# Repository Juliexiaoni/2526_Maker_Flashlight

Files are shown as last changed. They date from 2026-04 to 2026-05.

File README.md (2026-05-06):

# 2526_Maker_Flashlight
Objectif : Concevoir une lampe d'éclairage sur un vélo afin d'augmenter la sécutité en étant plus visible. 

### Cahier des charges : 
- 3 modes d’éclairages
- Étanche
- Bonus pour le rendre avancée : énergie solaire, allumage automatique (capteur luminosité)

### Planning prévisionnel : 
1. Etablir une analyse fonctionnelle et la BOM
2. Schématique et routage conception électronique
3. CAO pour le boitier
4. Assemblage et test

Le boîtier consiste à réaliser un suppport qui se clipse sur une attache en caoutchouc. 
Support Flashlight

WhatsApp Image 2026-05-06 at 15 49 47 (1)
WhatsApp Image 2026-05-06 at 15 49 47
WhatsApp Image 2026-05-06 at 15 54 11

La distance laissée entre les composants de la couche arrière et le support permet d’utiliser le bouton pour allumer et éteindre la lumière.

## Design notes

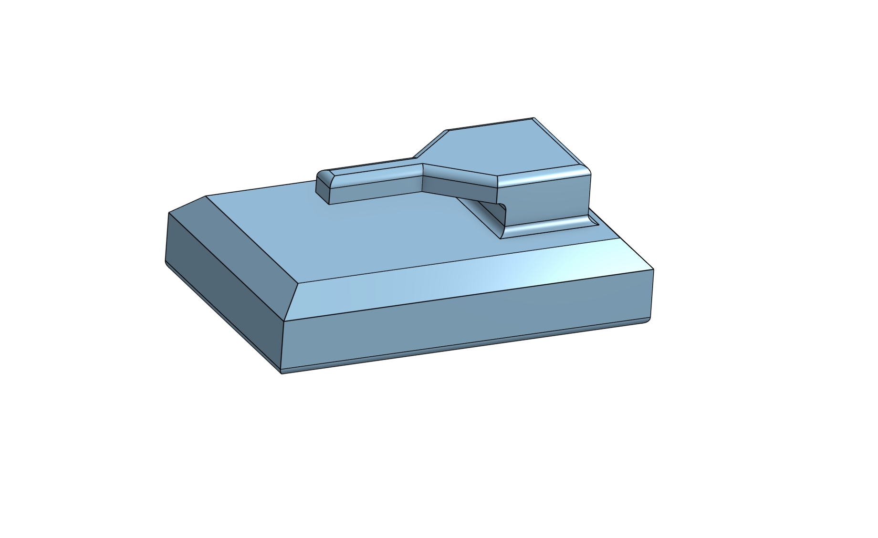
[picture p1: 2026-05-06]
Impression 3D/Support Flashlight.png

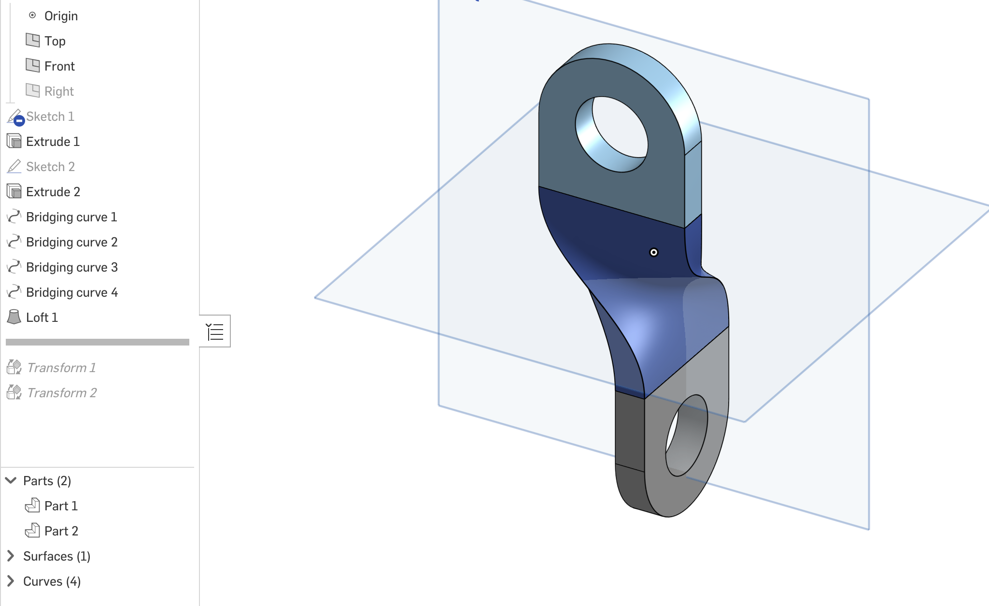
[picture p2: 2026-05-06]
Impression 3D/Exercice 2.png

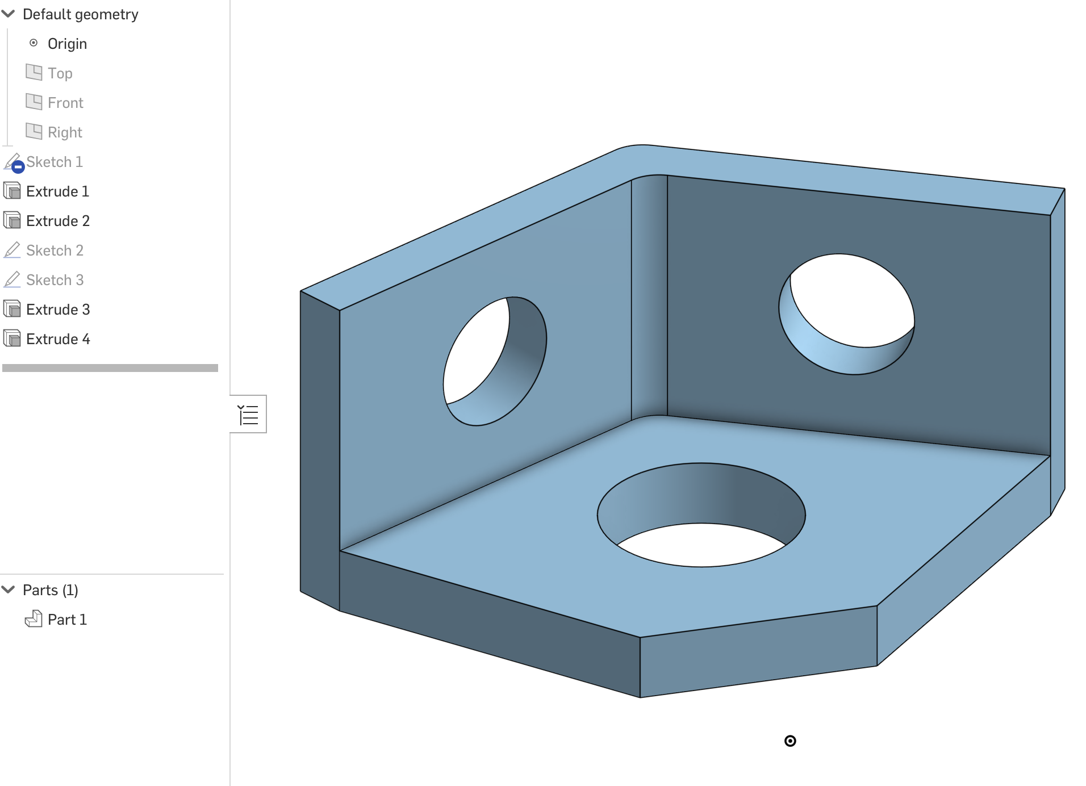
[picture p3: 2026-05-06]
Impression 3D/Exercice 1.png

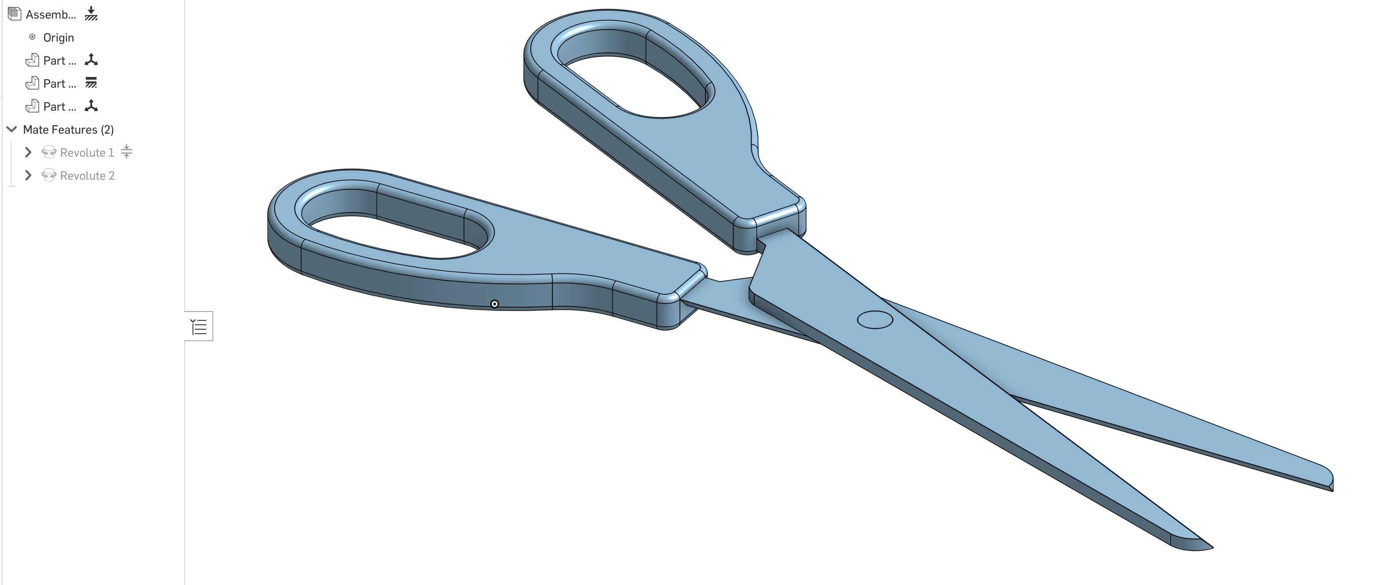
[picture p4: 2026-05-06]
Impression 3D/Exercice 3.png

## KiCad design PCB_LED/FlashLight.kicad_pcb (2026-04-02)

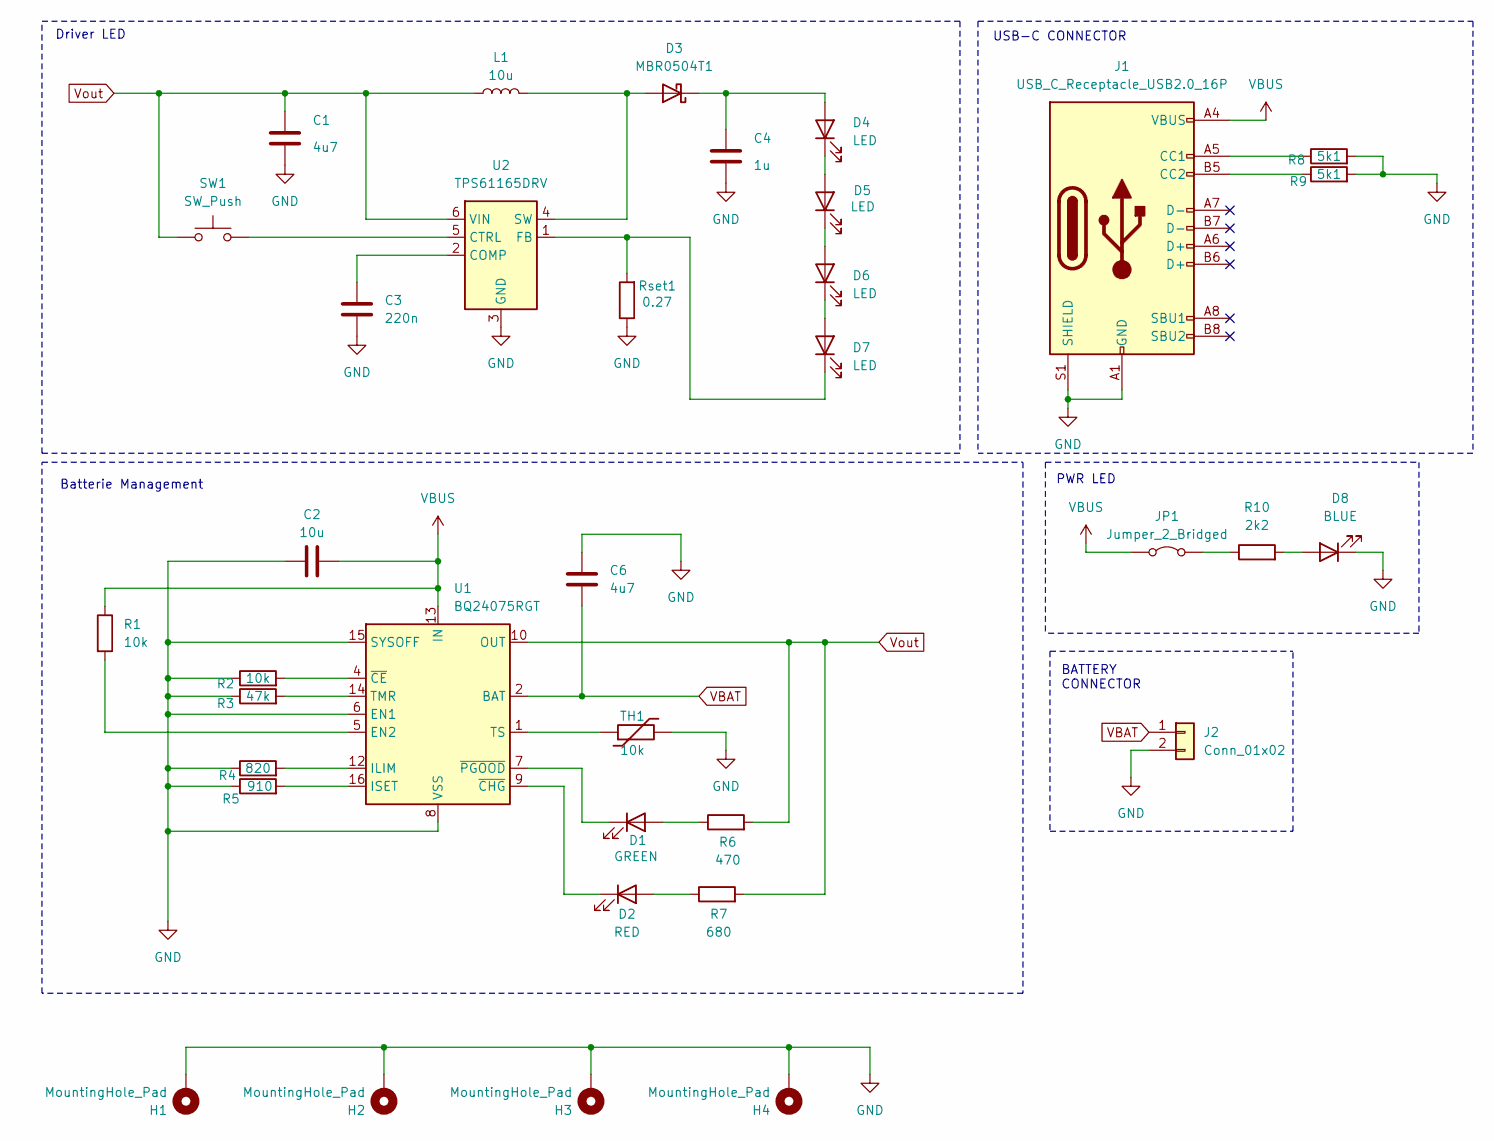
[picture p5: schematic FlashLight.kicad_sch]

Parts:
C1, C6: 4u7; C_0603_1608Metric_Pad1.08x0.95mm_HandSolder
C2: 10u; C_0603_1608Metric_Pad1.08x0.95mm_HandSolder
C3: 220n; C_0603_1608Metric_Pad1.08x0.95mm_HandSolder
C4: 1u; C_0603_1608Metric_Pad1.08x0.95mm_HandSolder
D1: GREEN; D_0603_1608Metric_Pad1.05x0.95mm_HandSolder
D2: RED; D_0603_1608Metric_Pad1.05x0.95mm_HandSolder
D3: MBR0504T1; D_SOD-123
D4, D5, D6, D7: LED; LED_Cree-XP
D8: BLUE; LED_0603_1608Metric_Pad1.05x0.95mm_HandSolder
H1, H2, H3, H4: MountingHole_Pad; MountingHole_2.2mm_M2_DIN965_Pad
J1: USB_C_Receptacle_USB2.0_16P; USB_C_Receptacle_GCT_USB4105-xx-A_16P_TopMnt_Horizontal
J2: Conn_01x02; JST_PH_B2B-PH-K_1x02_P2.00mm_Vertical
JP1: Jumper_2_Bridged; SolderJumper-2_P1.3mm_Open_Pad1.0x1.5mm
L1: 10u; L_Wuerth_WE-PD-Typ-7345
R1, R2: 10k; R_0402_1005Metric_Pad0.72x0.64mm_HandSolder
R3: 47k; R_0402_1005Metric_Pad0.72x0.64mm_HandSolder
R4: 820; R_0402_1005Metric_Pad0.72x0.64mm_HandSolder
R5: 910; R_0402_1005Metric_Pad0.72x0.64mm_HandSolder
R6: 470; R_0402_1005Metric_Pad0.72x0.64mm_HandSolder
R7: 680; R_0402_1005Metric_Pad0.72x0.64mm_HandSolder
R8, R9: 5k1; R_0402_1005Metric_Pad0.72x0.64mm_HandSolder
R10: 2k2; R_0402_1005Metric_Pad0.72x0.64mm_HandSolder
Rset1: 0.27; R_0402_1005Metric_Pad0.72x0.64mm_HandSolder
SW1: SW_Push; SW_PUSH_6mm
TH1: 10k; R_0603_1608Metric_Pad0.98x0.95mm_HandSolder
U1: BQ24075RGT; VQFN-16-1EP_3x3mm_P0.5mm_EP1.6x1.6mm
U2: TPS61165DRV; WSON-6-1EP_2x2mm_P0.65mm_EP1x1.6mm

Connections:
GND: C1.2, C2.1, C3.2, C4.2, C6.1, D8.1 (K), H1.1, H2.1, H3.1, H4.1, J1.A1 (GND), J1.A12 (GND), J1.B1 (GND), J1.B12 (GND), J1.S1 (SHIELD), J2.2, R2.1, R3.1, R4.1, R5.1, R8.2, R9.2, Rset1.1, TH1.2, U1.6 (EN1), U1.8 (VSS), U1.15 (SYSOFF), U1.17 (VSS), U2.3 (GND), U2.7 (GND)
unnamed: D1.2 (A), R6.1
unnamed: D1.1 (K), U1.7 (~PGOOD)
unnamed: D2.2 (A), R7.1
unnamed: D2.1 (K), U1.9 (~CHG)
unnamed: D3.2 (A), L1.2, U2.4 (SW)
unnamed: C4.1, D3.1 (K), D4.2 (A)
unnamed: D4.1 (K), D5.2 (A)
unnamed: D5.1 (K), D6.2 (A)
unnamed: D6.1 (K), D7.2 (A)
unnamed: D7.1 (K), Rset1.2, U2.1 (FB)
unnamed: D8.2 (A), R10.2
unnamed: J1.A5 (CC1), R8.1
unnamed: J1.B5 (CC2), R9.1
unnamed: JP1.2 (B), R10.1
unnamed: R1.2, U1.5 (EN2)
unnamed: R4.2, U1.12 (ILIM)
unnamed: R5.2, U1.16 (ISET)
unnamed: R3.2, U1.14 (TMR)
unnamed: TH1.1, U1.1 (TS)
unnamed: R2.2, U1.4 (~CE)
unnamed: C3.1, U2.2 (COMP)
unnamed: SW1.2, U2.5 (CTRL)
VBAT: C6.2, J2.1, U1.2 (BAT), U1.3 (BAT)
VBUS: C2.2, J1.A4 (VBUS), J1.A9 (VBUS), J1.B4 (VBUS), J1.B9 (VBUS), JP1.1 (A), R1.1, U1.13 (IN)
Vout: C1.1, L1.1, R6.2, R7.2, SW1.1, U1.10 (OUT), U1.11 (OUT), U2.6 (VIN)

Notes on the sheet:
Driver LED
Batterie Management
BATTERY CONNECTOR
PWR LED
USB-C CONNECTOR

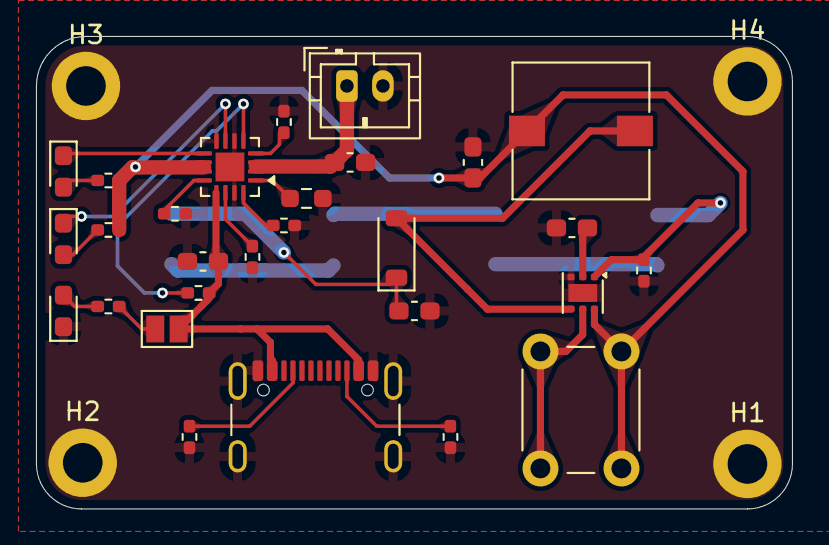
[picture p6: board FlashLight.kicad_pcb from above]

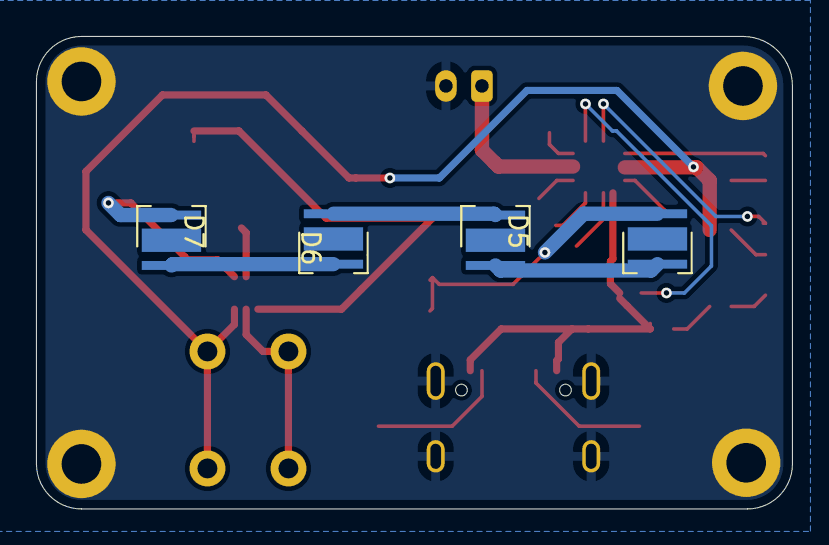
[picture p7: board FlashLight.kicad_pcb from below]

Board: 2 copper layers, 42.0 x 26.2 mm, 36 parts (4 on the bottom side), 26 nets.

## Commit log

2026-03-26 Schématique_LED
    [FlashLight.kicad_pcb, FlashLight.kicad_sch]
2026-03-30 Driver TI
    [FlashLight.kicad_sch]
2026-03-30 Modif 1
    [FlashLight.kicad_sch]
